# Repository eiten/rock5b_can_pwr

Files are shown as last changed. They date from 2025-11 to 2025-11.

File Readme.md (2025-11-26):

# ROCK 5B High-Power CAN-Bus & Power HAT ("The Beast")

> 🌍 **Languages:** [English](Readme.md) | [Deutsch](Readme.de.md)

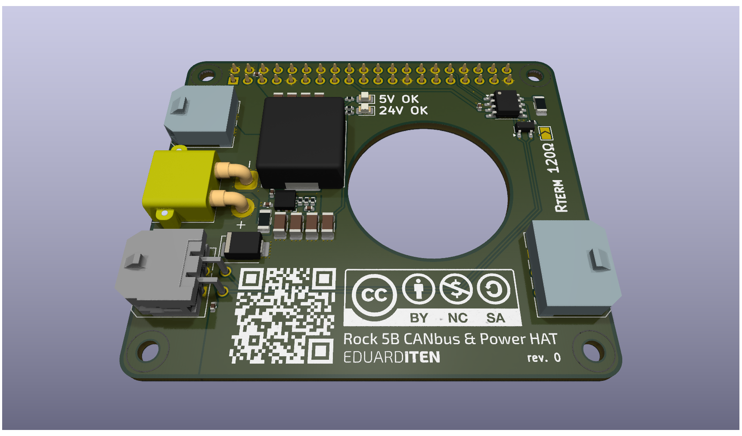
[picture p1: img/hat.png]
3D view


## Table of Contents

<!-- @import "[TOC]" {cmd="toc" depthFrom=1 depthTo=6 orderedList=false} -->

<!-- code_chunk_output -->

- [ROCK 5B High-Power CAN-Bus & Power HAT ("The Beast")](#rock-5b-high-power-can-bus--power-hat-the-beast)
  - [Table of Contents](#table-of-contents)
  - [About the Project](#about-the-project)
  - [Features & Technical Specifications](#features--technical-specifications)
    - [⚡ Power Distribution (Split-Path Architecture)](#-power-distribution-split-path-architecture)
    - [**🚀 Native CAN-Bus**](#-native-can-bus)
    - [🔌 Poka-Yoke Connectors](#-poka-yoke-connectors)
  - [Pinout](#pinout)
    - [J102 - TOOLHEAD (4-Pin Micro-Fit Square)](#j102---toolhead-4-pin-micro-fit-square)
    - [J103 - SPIDER / MCU (3-Pin Micro-Fit Row)](#j103---spider--mcu-3-pin-micro-fit-row)
    - [J_LCD - MONITOR (4-Pin Micro-Fit Row)](#j_lcd---monitor-4-pin-micro-fit-row)
  - [Status LEDs ("Mouse Cinema")](#status-leds-mouse-cinema)
  - [Software Configuration (Radxa OS / Armbian)](#software-configuration-radxa-os--armbian)
    - [1. Enable Overlay](#1-enable-overlay)
    - [2. Configure Interface](#2-configure-interface)
    - [3. Klipper Configuration](#3-klipper-configuration)
  - [Manufacturing Notes (BOM & PCB)](#manufacturing-notes-bom--pcb)
  - [License](#license)

<!-- /code_chunk_output -->

## About the Project

This HAT was developed to turn the **Radxa Rock 5B** into the ultimate control center for high-performance laser plotters and 3D printers (Klipper). It addresses the specific weaknesses of standard solutions:

1. **Stable Power Supply:** Delivers massive 5.2V/6A for the SBC and peripheral USB-C touchscreens.  
2. **Native CAN Performance:** Uses the integrated CAN controller of the RK3588 instead of slow SPI bridges.  
3. **Thermal Management:** A special "donut" design allows the CPU fan to draw fresh air through the PCB.

## Features & Technical Specifications

### ⚡ Power Distribution (Split-Path Architecture)

The board separates power paths for maximum safety and performance:

* **Input:** 24V DC via reverse-polarity protected **XT30 (High Current)** connector.  
* **High-Power Path (Laser/Toolhead):**  
  * Massive 3-layer copper connection.  
  * Direct 24V passthrough to toolhead (up to 120W+ possible, depending on power supply).  
  * Protected by **SMBJ24A TVS diode** against inductive voltage spikes (Back-EMF).  
* **Logic Path (SBC & Display):**  
  * Protected by **2A Fast** fuse (Littelfuse 0466 series, 63V rating).  
  * **DC/DC Converter:** TI **TPS56637** Synchronous Buck Converter.  
  * Output: **5.2V** (compensates for voltage drop on cables) at up to **6A**.

### **🚀 Native CAN-Bus**

* No USB adapters or SPI chips (MCP2515) required.  
* Uses the native **CAN1 Controller** of the RK3588 (Pins 32/33).  
* **Transceiver:** TI SN65HVD230 (3.3V Logic).  
* **ESD Protection:** NUP2105L diode on data lines.  
* **Termination:** 120Ω termination resistor switchable via solder jumper (JP1).

### 🔌 Poka-Yoke Connectors

Uses **Molex Micro-Fit 3.0** with different pin counts to physically prevent fatal miswiring (e.g., 24V to 5V input).

| Port | Type | Pins | Description |
| :---- | :---- | :---- | :---- |
| **24V IN** | **XT30** | 2 | Main input from power supply. |
| **TOOLHEAD** | **Micro-Fit** | 2x2 (4-Pin) | 24V High-Current + CAN data to laser/print head. |
| **CONTROLLER** | **Micro-Fit** | 1x3 (3-Pin) | Pure data connection to MCU mainboard (e.g., Spider). |
| **MONITOR** | **Micro-Fit** | 1x4 (4-Pin) | 2x 5.2V / 2x GND for powering external displays. |

## Pinout

### J102 - TOOLHEAD (4-Pin Micro-Fit Square)

*This is where the laser or print head is connected.*

1. **24V** (Unfused, High Power)  
2. **GND**  
3. **CAN_L**  
4. **CAN_H**

### J103 - SPIDER / MCU (3-Pin Micro-Fit Row)

*Connection to mainboard. Galvanically isolated from 24V.*

1. **GND**  
2. **CAN_L**  
3. **CAN_H**

### J_LCD - MONITOR (4-Pin Micro-Fit Row)

*Power supply for USB-C monitors or HDMI displays.*

1. **+5.2V**  
2. **+5.2V**  
3. **GND**  
4. **GND**

## Status LEDs ("Mouse Cinema")

The board features two labeled LEDs for quick diagnosis:

* 24V input present (fuse intact).  
* 5.2V logic voltage stable (Power Good signal from TPS56637).  

## Software Configuration (Radxa OS / Armbian)

Since the native CAN controller is used, setup is extremely simple.

### 1. Enable Overlay

Add the overlay for the CAN1 controller.  
Via rsetup:  
`Hardware -> Overlays -> Enable CAN1-M1 on GPIO3 (Pins 32/33)`.  
Manually (`/boot/extlinux/extlinux.conf`):  
Add `rk3588-can1-m1` to the `fdtoverlays` line.

### 2. Configure Interface

Create `/etc/network/interfaces.d/can0` for autostart:  
```
allow-hotplug can0 
iface can0 can static  
    bitrate 500000  
    up ip link set $IFACE txqueuelen 1024
```

### 3. Klipper Configuration

In printer.cfg:
```
[mcu]  
canbus_uuid: <your_uuid>  
# No more "serial:" entries!
```

## Manufacturing Notes (BOM & PCB)

* **PCB Specs:** 4-Layer (Signal / GND / Power / Signal), 1oz copper.  
* **GPIO Header:** A **Stacking Header (Extra Tall, min. 11mm spacer height)** is absolutely required to provide clearance from the CPU cooler.  
* **Soldering:** Due to massive ground and power planes, a preheater plate (printer heated bed) or preheating in an oven (100°C) is strongly recommended.

**Critical Components (LCSC):**

* Buck Converter: **TPS56637RPAR**  
* Inductor: **MDA1350-2R2M** (2.2µH, Isat > 15A, Shielded)  
* Transceiver: **SN65HVD230**  
* Fuse: **Littelfuse 0466002.NRHF** (2A, **63V Rating!**)

Disclaimer:  
This design works with high currents and voltages. Use at your own risk. Make sure cable cross-sections are rated for the load of your laser/hotend.

## License

This project is licensed under the **Creative Commons Attribution-NonCommercial-ShareAlike 4.0 International License** (CC BY-NC-SA 4.0).



This means you are free to:
- **Share** — copy and redistribute the material in any medium or format
- **Adapt** — remix, transform, and build upon the material

Under the following terms:
- **Attribution** — You must give appropriate credit, provide a link to the license, and indicate if changes were made
- **NonCommercial** — You may not use the material for commercial purposes
- **ShareAlike** — If you remix, transform, or build upon the material, you must distribute your contributions under the same license

For the full license text, visit: https://creativecommons.org/licenses/by-nc-sa/4.0/

---

> **Note:** The original documentation is in German ([Readme.de.md](Readme.de.md)). This English version is a translation for international users.

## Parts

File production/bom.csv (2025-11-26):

Designator | Footprint | Quantity | Value | LCSC Part #
C101, C102, C103, C105 | 1206 | 4 | 4u7 | C29823
C104, C106, C107, C108, C110 | 0402 | 5 | 100n | C1525
C109 | 0402 | 1 | 100p | C1546
C112, C113, C114, C115 | 1206 | 4 | 22uF | C87996
D101 | D_SMB | 1 | SMBJ24A | C224017
D102 | 0805 | 1 | red | C84256
D103 | 0805 | 1 | green | C2297
D104 | SOT-23 | 1 | NUP2105L | C14486
F101 | 1206 | 1 | 0466002.NRHF | C3105
J101 | PinSocket_2x20_P2.54mm_Vertical | 1 | GPIO | C5307344
J102 | AMASS_XT30PW-M_1x02_P2.50mm_Horizontal | 1 | XT30 | C431092
J103 | Molex_Micro-Fit_3.0_43045-0400_2x02_P3.00mm_Horizontal | 1 | Tool | C122413
J104 | Molex_Micro-Fit_3.0_43650-0300_1x03_P3.00mm_Horizontal | 1 | Controller | C503478
J105 | Molex_Micro-Fit_3.0_43650-0200_1x02_P3.00mm_Horizontal | 1 | Monitor | C192562
L101 | L_Changjiang_FXL1350 | 1 | 2u2 | C2847569
R101, R102, R105 | 0402 | 3 | 20k | C25765
R103 | 1206 | 1 | 0R | C17888
R104 | 0402 | 1 | 3k3 | C270612
R106 | 0402 | 1 | 76.8k | C26987
R107 | 0402 | 1 | 10k | 0402WGF1002TCE
R108 | 0402 | 1 | 120R | C25079
U101 | RPA0010A | 1 | TPS56637RPAR | C841386
U102 | SOIC-8_3.9x4.9mm_P1.27mm | 1 | SN65HVD230 | C12084

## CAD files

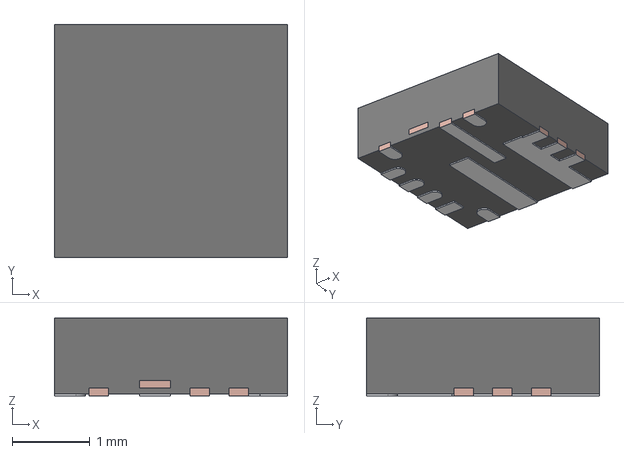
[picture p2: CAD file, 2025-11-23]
3D/RPA0010A.stp
3.00 x 3.00 x 1.00 mm
FRAME
MOLD

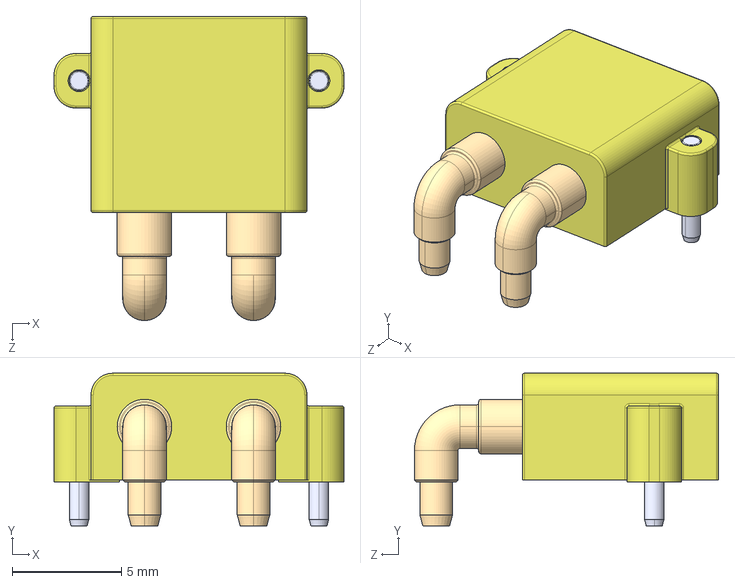
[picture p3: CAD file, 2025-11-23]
3D/XT30PW-M--3DModel-STEP-269445.STEP
13.3 x 7.00 x 14.0 mm

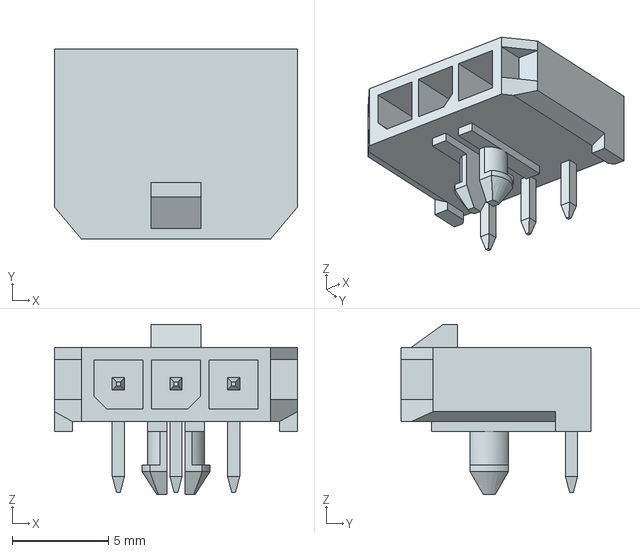
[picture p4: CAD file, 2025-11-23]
3D/436500300.stp
12.7 x 9.90 x 8.87 mm

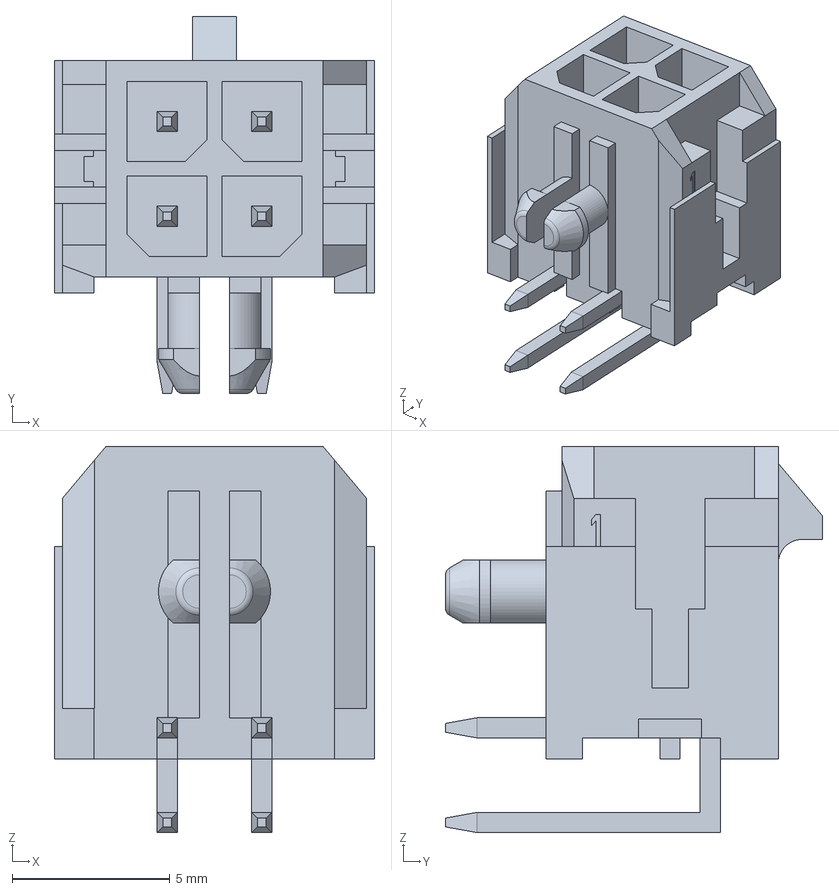
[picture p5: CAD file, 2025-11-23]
3D/430450400.stp
10.2 x 11.9 x 12.2 mm

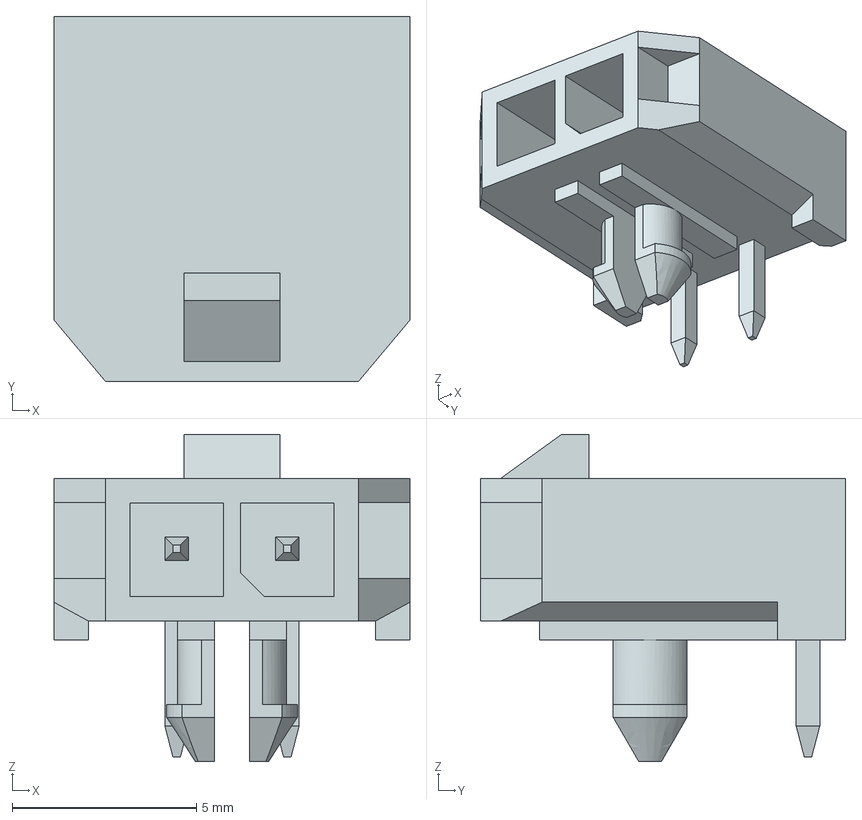
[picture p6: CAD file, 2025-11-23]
3D/436500200.stp
9.65 x 9.90 x 8.87 mm

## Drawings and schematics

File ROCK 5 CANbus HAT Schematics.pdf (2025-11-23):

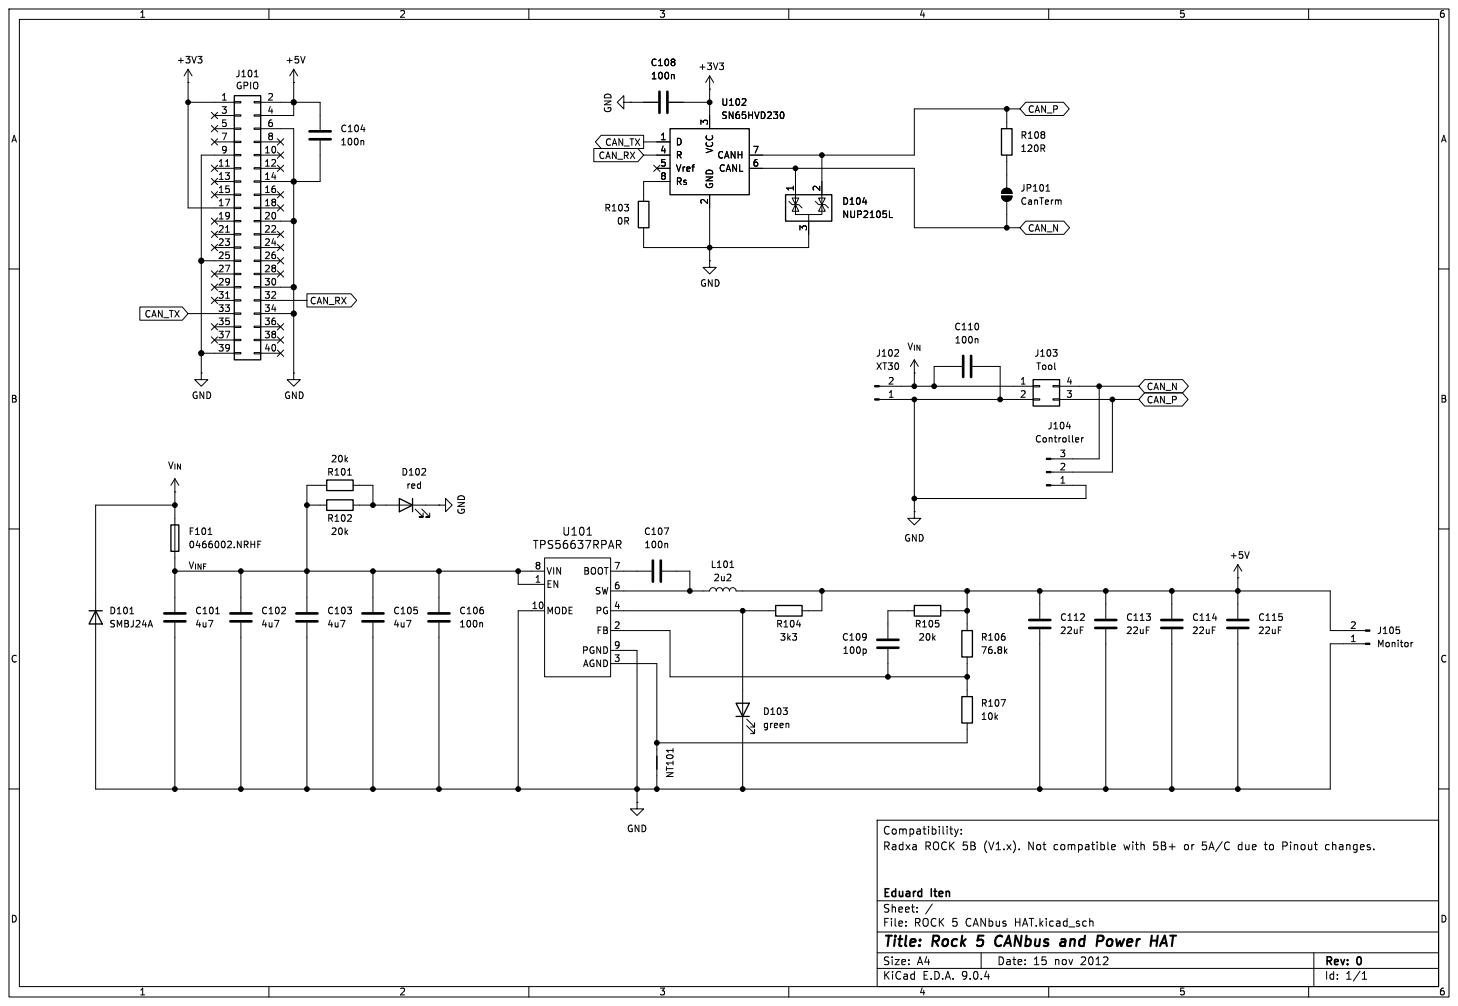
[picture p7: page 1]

Id: 1/1 Title: Rock 5 CANbus and Power HAT

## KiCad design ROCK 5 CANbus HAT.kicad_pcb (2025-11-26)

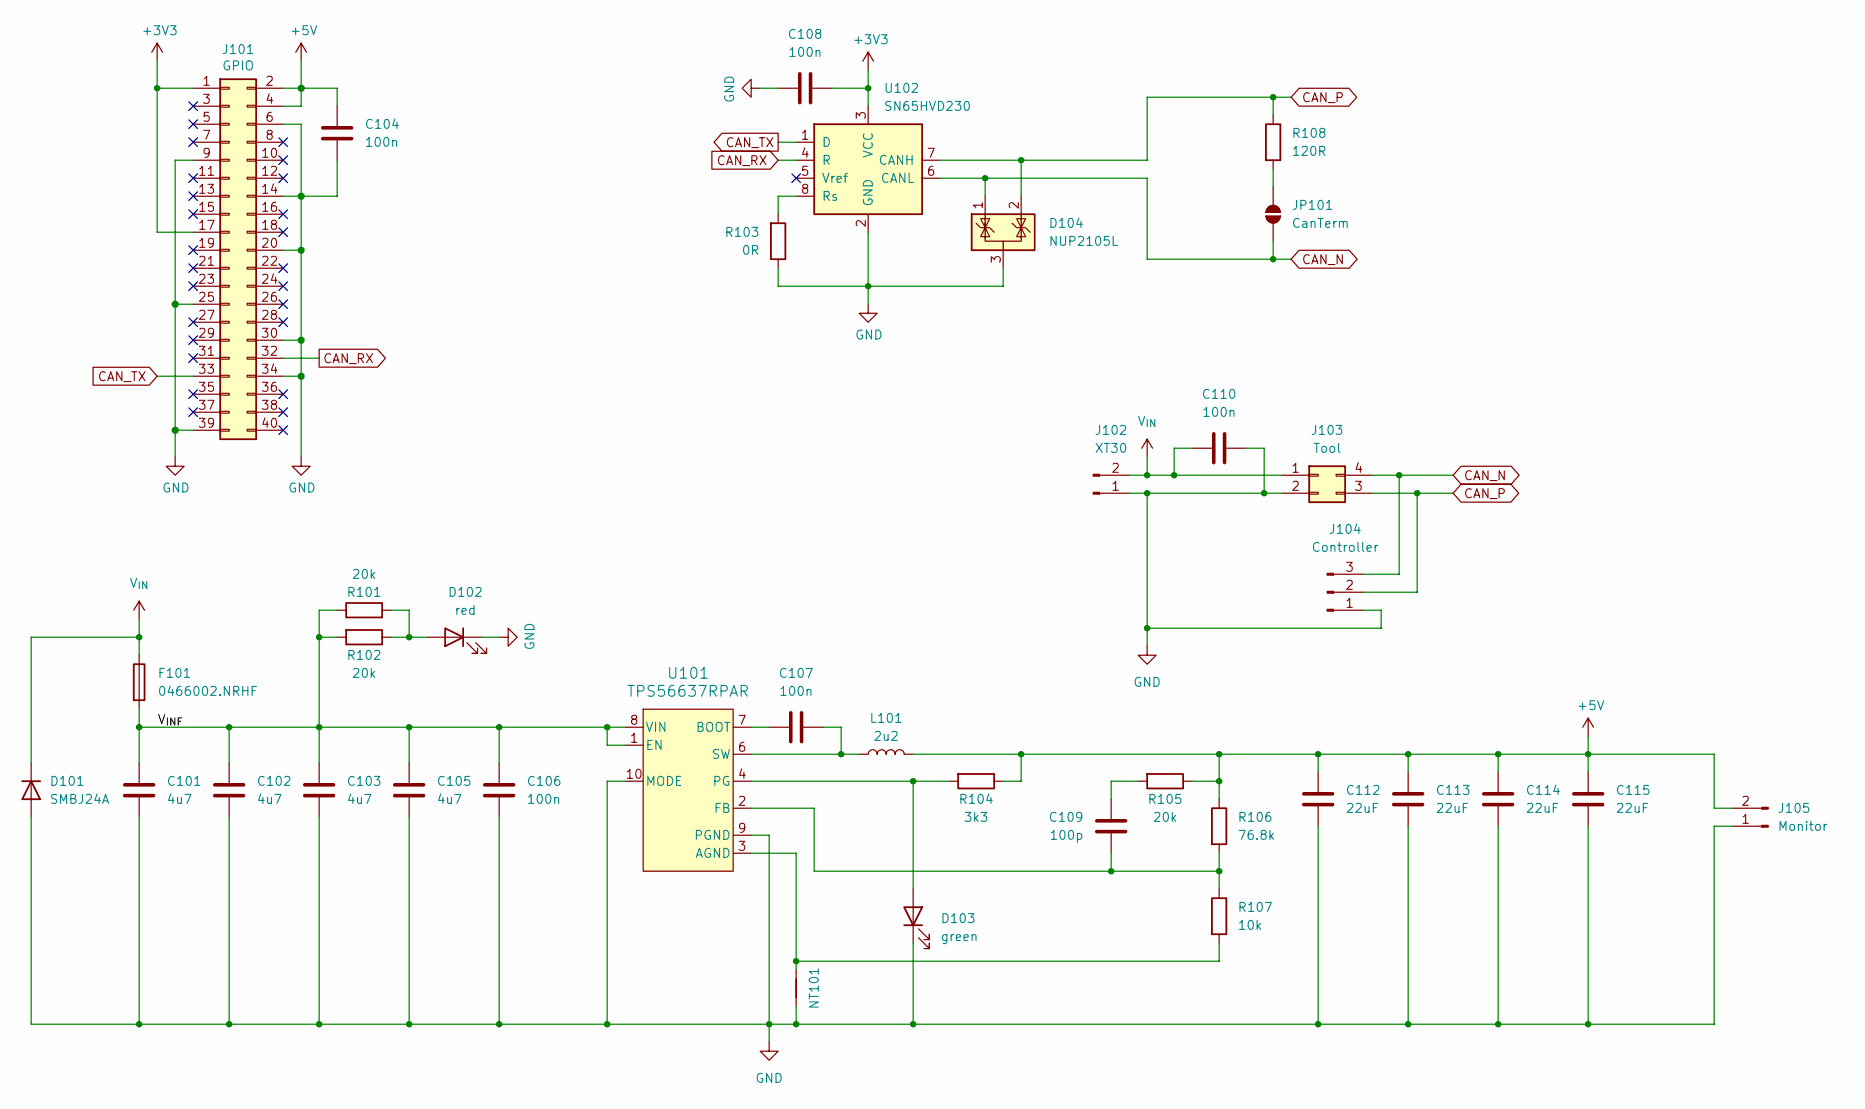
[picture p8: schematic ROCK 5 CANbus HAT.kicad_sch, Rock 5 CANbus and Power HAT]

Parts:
C101, C102, C103, C105: 4u7; C_1206_3216Metric; Manufacturer Part # 1206B475K500NT; LCSC Part # C29823
C104, C106, C107, C108, C110: 100n; C_0402_1005Metric; Manufacturer Part # CL05B104KO5NNNC; LCSC Part # C1525
C109: 100p; C_0402_1005Metric; Manufacturer Part # 0402CG101J500NT; LCSC Part # C1546
C112, C113, C114, C115: 22uF; C_1206_3216Metric; Manufacturer Part # CL31B226KPHNNNE; LCSC Part # C87996
D101: SMBJ24A; D_SMB; Manufacturer Part # SMBJ24A; LCSC Part # C224017
D102: red; LED_0805_2012Metric; Manufacturer Part # NCD0805R1; LCSC Part # C84256
D103: green; LED_0805_2012Metric; Manufacturer Part # KT-0805G; LCSC Part # C2297
D104: NUP2105L; SOT-23; Manufacturer Part # NUP2105LT1G; LCSC Part # C14486
F101: 0466002.NRHF; Fuse_1206_3216Metric; Manufacturer Part # 0466002.NRHF; LCSC Part # C3105
J101: GPIO; PinSocket_2x20_P2.54mm_Vertical; Manufacturer Part # C5307344; LCSC Part # C5307344
J102: XT30; AMASS_XT30PW-M_1x02_P2.50mm_Horizontal; Manufacturer Part # XT30PW-M30.G.Y; LCSC Part # C431092
J103: Tool; Molex_Micro-Fit_3.0_43045-0400_2x02_P3.00mm_Horizontal; Manufacturer Part # 430450400; LCSC Part # C122413
J104: Controller; Molex_Micro-Fit_3.0_43650-0300_1x03_P3.00mm_Horizontal; Manufacturer Part # 436500300; LCSC Part # C503478
J105: Monitor; Molex_Micro-Fit_3.0_43650-0200_1x02_P3.00mm_Horizontal; Manufacturer Part # 436500200; LCSC Part # C192562
JP101: CanTerm; SolderJumper-2_P1.3mm_Open_TrianglePad1.0x1.5mm
L101: 2u2; L_Changjiang_FXL1350; Manufacturer Part # MDA1350-2R2M; LCSC Part # C2847569
NT101: NetTie_2; NetTie-2_SMD_Pad0.5mm
R101, R102, R105: 20k; R_0402_1005Metric; Manufacturer Part # 0402WGF2002TCE; LCSC Part # C25765
R103: 0R; R_1206_3216Metric_Pad1.30x1.75mm_HandSolder; Manufacturer Part # 1206W4F0000T5E; LCSC Part # C17888
R104: 3k3; R_0402_1005Metric; Manufacturer Part # 0402WGF330KTCE; LCSC Part # C270612
R106: 76.8k; R_0402_1005Metric; Manufacturer Part # 0402WGF7682TCE; LCSC Part # C26987
R107: 10k; R_0402_1005Metric; Manufacturer Part # 0402WGF1200TCE; LCSC Part # 0402WGF1002TCE
R108: 120R; R_0402_1005Metric; Manufacturer Part # 0402WGF1200TCE; LCSC Part # C25079
U101: TPS56637RPAR; RPA0010A; Manufacturer Part # TPS56637RPAR; LCSC Part # C841386
U102: SN65HVD230; SOIC-8_3.9x4.9mm_P1.27mm; Manufacturer Part # SN65HVD230DR; LCSC Part # C12084

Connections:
+3V3: C108.2, J101.1, J101.17, U102.3 (VCC)
+5V: C104.2, C112.1, C113.1, C114.1, C115.1, J101.2, J101.4, J105.2, L101.2, R104.1, R105.1, R106.1
/V_{INF}: C101.1, C102.1, C103.1, C105.1, C106.1, F101.2, R101.1, R102.2, U101.1 (EN), U101.8 (VIN)
CAN_N: D104.1 (K), J103.4, J104.3, JP101.1 (A), U102.6 (CANL)
CAN_P: D104.2 (K), J103.3, J104.2, R108.1, U102.7 (CANH)
CAN_RX: J101.32, U102.4 (R)
CAN_TX: J101.33, U102.1 (D)
GND: C101.2, C102.2, C103.2, C104.1, C105.2, C106.2, C108.1, C110.1, C112.2, C113.2, C114.2, C115.2, D101.2 (A), D102.1 (K), D103.1 (K), D104.3 (A), J101.6, J101.9, J101.14, J101.20, J101.25, J101.30, J101.34, J101.39, J102.1, J103.2, J104.1, J105.1, NT101.2, R103.1, U101.9 (PGND), U101.10 (MODE), U102.2 (GND)
unnamed: C109.1, R105.2
unnamed: D102.2 (A), R101.2, R102.1
unnamed: D103.2 (A), R104.2, U101.4 (PG)
unnamed: JP101.2 (B), R108.2
unnamed: NT101.1, R107.2, U101.3 (AGND)
unnamed: C107.1, U101.7 (BOOT)
unnamed: C109.2, R106.2, R107.1, U101.2 (FB)
unnamed: C107.2, L101.1, U101.6 (SW)
unnamed: R103.2, U102.8 (Rs)
V_{IN}: C110.2, D101.1 (K), F101.1, J102.2, J103.1

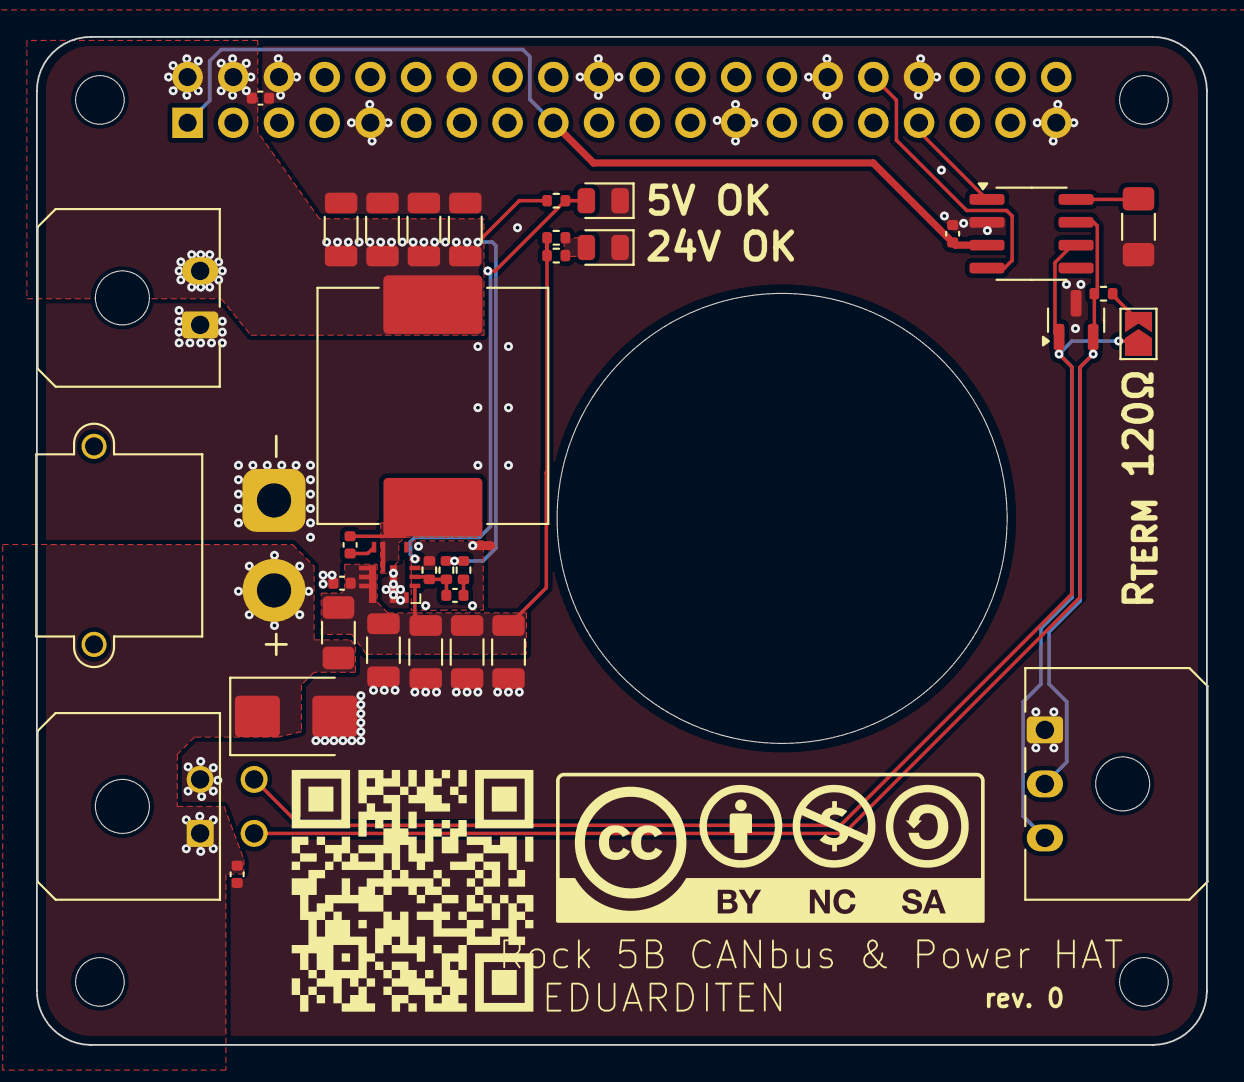
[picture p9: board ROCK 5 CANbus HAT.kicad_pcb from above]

Board: 4 copper layers, 65.0 x 56.0 mm, 41 parts (1 on the bottom side), 18 nets.

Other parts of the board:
MH1, MH2, MH3, MH4: MountingHole_2.7mm_M2.5

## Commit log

2025-11-23 Initial commit: Beast HAT rev. 0
    [430450400.stp, 436500200.stp, 436500300.stp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]
2025-11-26 Add production files and update PCB layout
    [ROCK 5 CANbus HAT.kicad_pcb, bom.csv, designators.csv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]
